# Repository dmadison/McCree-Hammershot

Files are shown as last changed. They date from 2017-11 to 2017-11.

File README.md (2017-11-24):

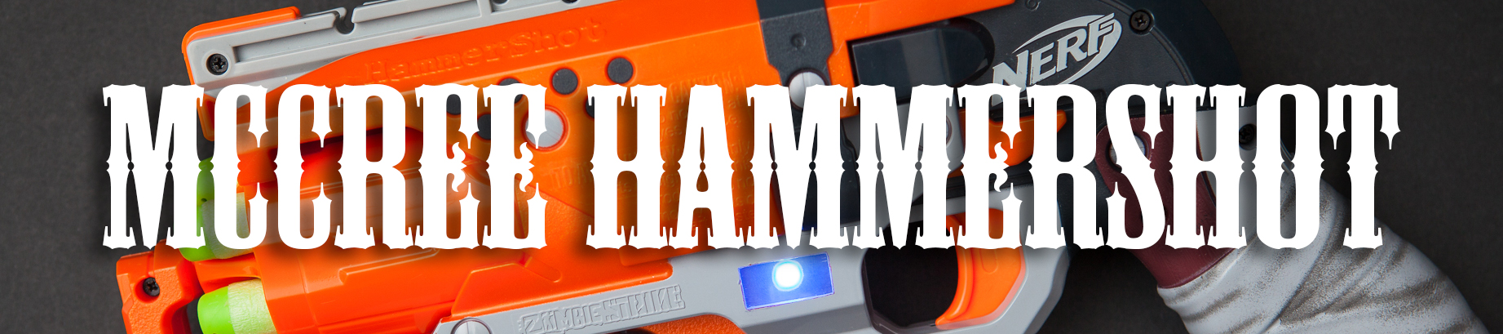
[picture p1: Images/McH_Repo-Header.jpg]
McCree Hammershot Header


## Synopsis
These are the associated files for my McCree Hammershot controller project! I turned a Nerf revolver into a custom controller for the character of [McCree](https://playoverwatch.com/en-us/heroes/mccree/) in *Overwatch*. The revolver contains an Arduino Pro Micro, an MPU-6050 IMU, and a host of other parts to handle McCree's controls. When paired with either a DDR dance pad or a Wii Nunchuk to handle his movement, I can use all of McCree's controls and play the game reasonably well.

For more information, check out the full build log on [PartsNotIncluded.com](http://www.partsnotincluded.com/projects/mccree-hammershot-controller/).

## Dependencies
The Hammershot program is dependent on the [CapacitiveSensor](https://github.com/PaulStoffregen/CapacitiveSensor/releases/tag/0.5.1), [Encoder](https://github.com/PaulStoffregen/Encoder/releases/tag/1.4.1) and [FastLED](https://github.com/FastLED/FastLED/releases/tag/v3.1.6) libraries. The Nunchuk code is dependent on the [WiiChuck](https://github.com/madhephaestus/WiiChuck/releases/tag/0.0.23) library to handle communication between the board and the Nunchuk. Both sketches are dependent on the Arduino IDE's built-in Keyboard, Mouse, and Wire libraries. The sketches were compiled using version 1.8.2 of the IDE.

I've linked to the specific library releases that work with this code. Note that future versions may not be compatible.

## License
The Arduino code, CAD files, and breakout PCB are licensed under the terms of the [GNU General Public License v3.0](https://www.gnu.org/licenses/gpl-3.0.en.html).

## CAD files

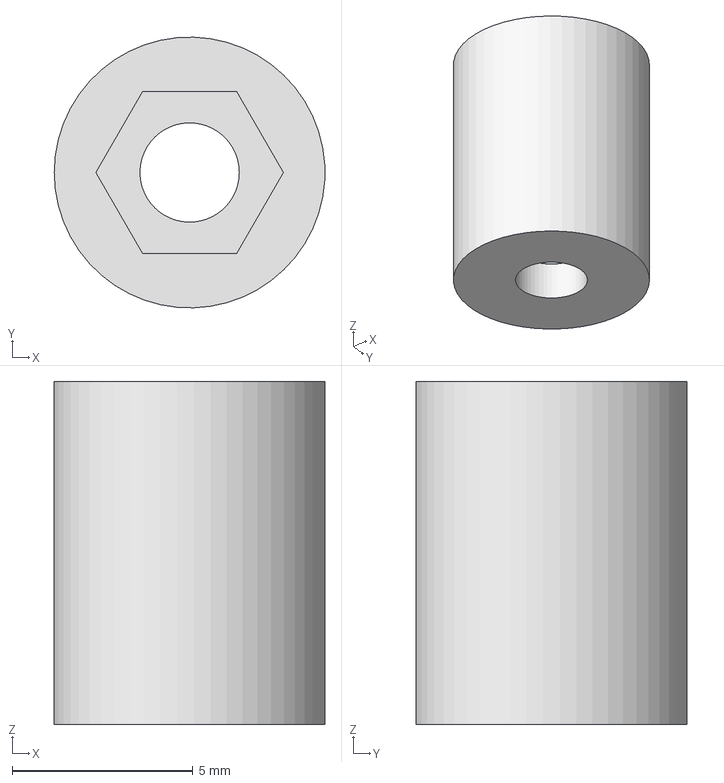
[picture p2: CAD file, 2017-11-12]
CAD/STEP/McH - Shell Connection Standoff.step
7.49 x 7.50 x 9.50 mm

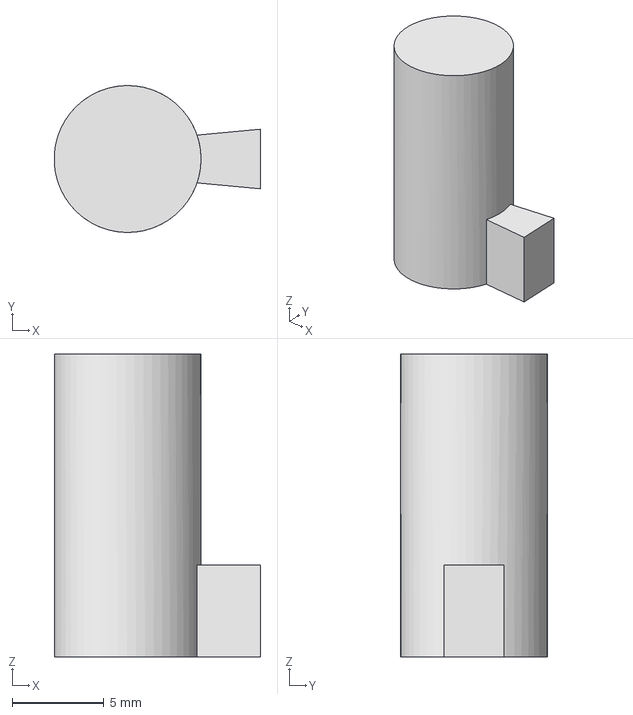
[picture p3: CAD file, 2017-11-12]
CAD/STEP/McH - Cylinder Wedge.step
11.2 x 8.00 x 16.5 mm

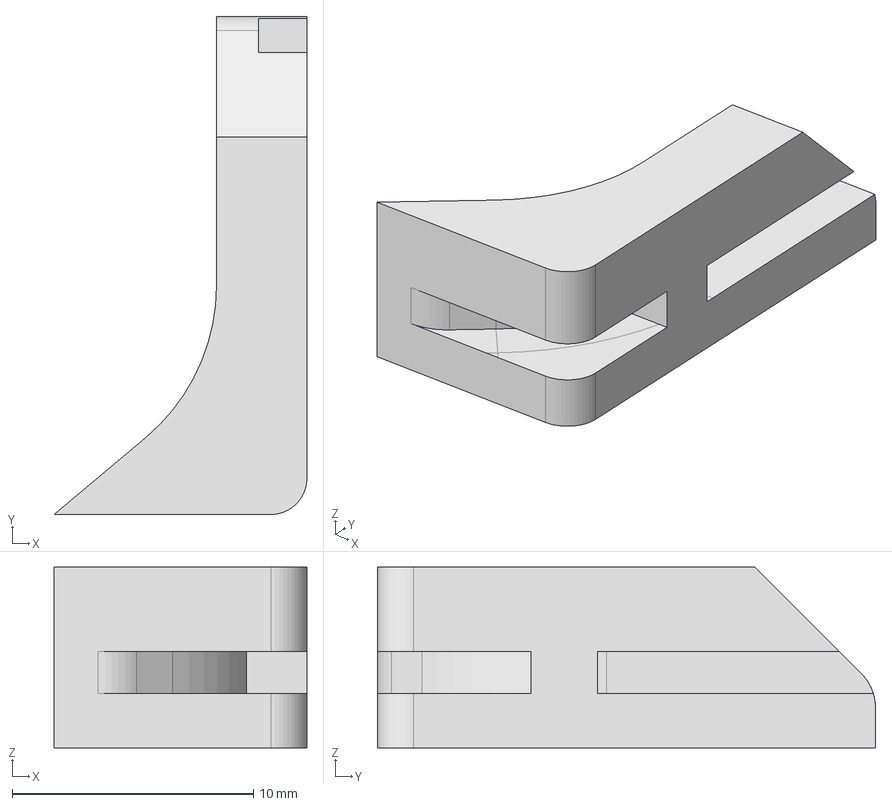
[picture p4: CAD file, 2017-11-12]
CAD/STEP/McH - Indicator Light Slot Support.step
10.5 x 20.7 x 7.50 mm

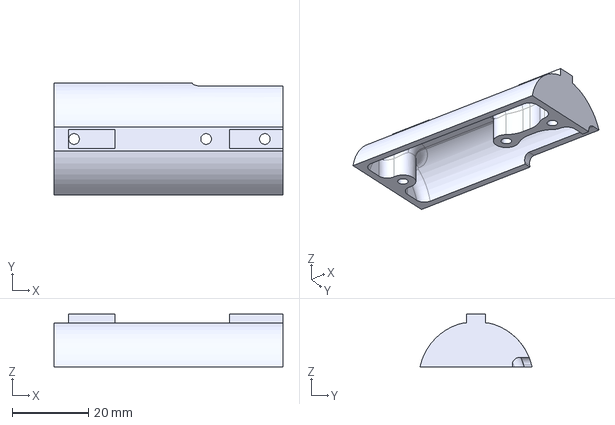
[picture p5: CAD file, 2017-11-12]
CAD/STEP/McH - PCB Mount.step
60.0 x 29.3 x 13.8 mm

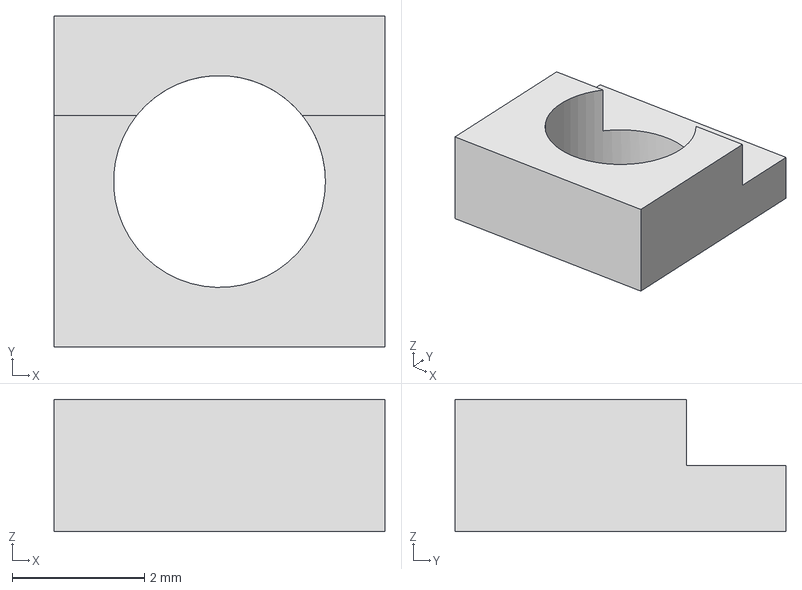
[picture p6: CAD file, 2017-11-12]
CAD/STEP/McH - MPU Capacitor Spacer.step
5.00 x 5.00 x 2.00 mm

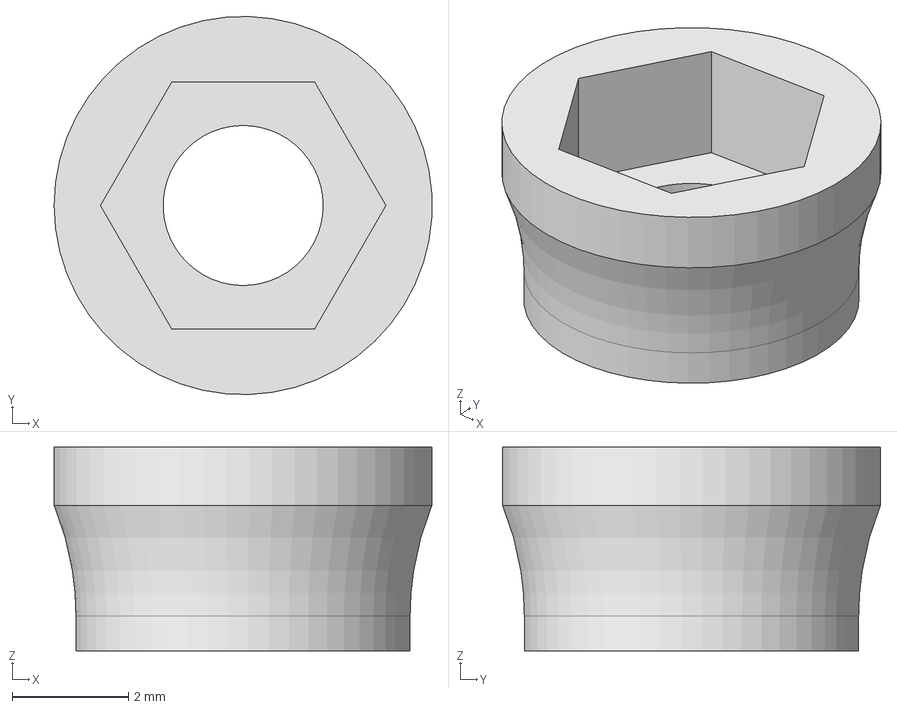
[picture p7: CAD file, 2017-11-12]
CAD/STEP/McH - Indicator Light Threaded Standoff.step
6.49 x 6.50 x 3.50 mm

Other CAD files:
CAD/STL/McH - Cylinder Wedge.stl
CAD/STL/McH - Indicator Light Slot Support.stl
CAD/STL/McH - Indicator Light Threaded Standoff.stl
CAD/STL/McH - MPU Capacitor Spacer.stl
CAD/STL/McH - PCB Mount.stl
CAD/STL/McH - Shell Connection Standoff.stl

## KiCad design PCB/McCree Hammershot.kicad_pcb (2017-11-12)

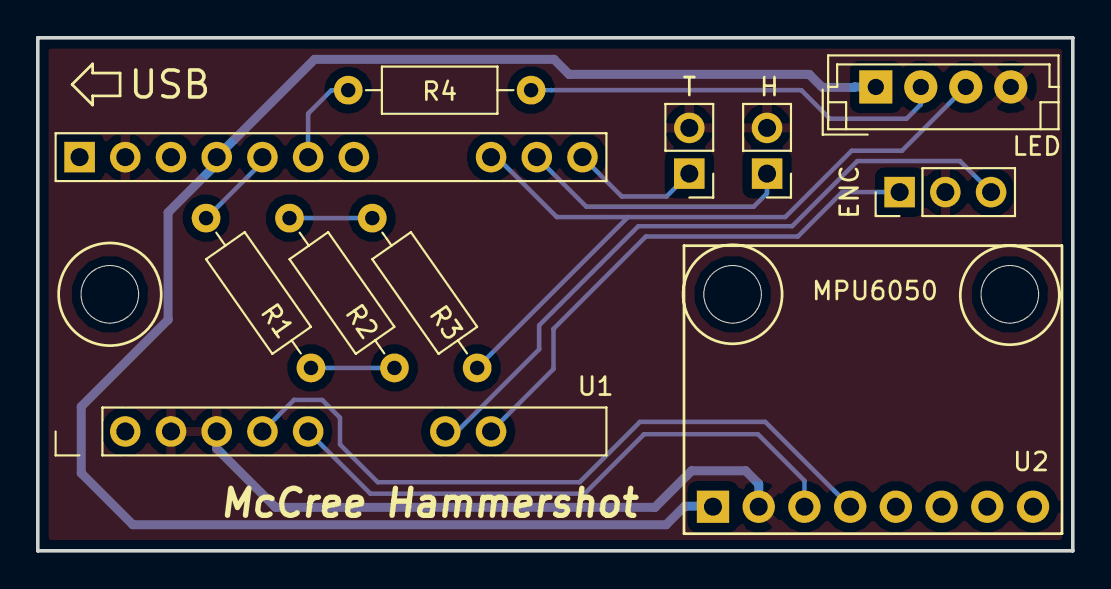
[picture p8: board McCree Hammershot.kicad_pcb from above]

Board: 4 copper layers, 57.5 x 28.5 mm, 10 parts (0 on the bottom side), 14 nets.

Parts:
ENC: Rotary Enc. Conn; Pin_Header_Straight_1x03_Pitch2.54mm
H: Hammer Conn; Pin_Header_Straight_1x02_Pitch2.54mm
LED: LED Conn; JST_EH_B04B-EH-A_04x2.50mm_Straight
R1, R2, R3: 1M; R_Axial_DIN0207_L6.3mm_D2.5mm_P10.16mm_Horizontal
R4: 470; R_Axial_DIN0207_L6.3mm_D2.5mm_P10.16mm_Horizontal
T: Trigger Conn; Pin_Header_Straight_1x02_Pitch2.54mm
U1: Arduino_Pro-Micro; Arduino_Pro-Micro_Headers_Gaps
U2: MPU6050; MPU6050_Breakout

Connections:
/+5V: LED.1, U1.VCC, U2.1
/CapSense: LED.3, R3.1, U1.14
/CapSource: R1.2, U1.A3
/EncoderA: ENC.1, U1.7
/EncoderB: ENC.3, U1.6
/GND: ENC.2, H.2, LED.4, T.2, U1.GND, U2.2
/Hammer: H.1, U1.16
/LED_Data: LED.2, R4.1
/SCL: U1.3, U2.3
/SDA: U1.2, U2.4
/Trigger: T.1, U1.10
unnamed: R1.1, R2.2
unnamed: R2.1, R3.2
unnamed: R4.2, U1.A2

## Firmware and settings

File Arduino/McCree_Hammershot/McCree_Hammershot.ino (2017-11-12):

/*
 *  Project     McCree Hammershot - Nerf Gun Code
 *  @author     David Madison
 *  @link       github.com/dmadison/McCree-Hammershot
 *  @license    GPLv3 - Copyright (c) 2017 David Madison
 *
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
 *  You should have received a copy of the GNU General Public License
 *  along with this program.  If not, see <http://www.gnu.org/licenses/>.
 */

#include <Wire.h>
#include <Mouse.h>
#include <Keyboard.h>

#include <Encoder.h>
#include <CapacitiveSensor.h>
#include <FastLED.h>

// -------- User Settings --------
// -- Game --
const float OverwatchSens = 7.5;   // User mouse sensitivity in Overwatch
const float AimSpeedFactor = 1.0;   // Factor to multiply aimspeed by
// -- LED --
const uint8_t LED_Brightness = 50;
const CRGB runningColor  = CRGB::Blue;
const CRGB pauseColor    = CRGB::Yellow;
const CRGB actionColor   = CRGB::Green;
const CRGB ultColor      = CRGB(0xFF3200); // Orange-ish red
const CRGB failsafeColor = CRGB::Purple;
// --------------------------------

// Tuning Options
const long    IMU_UpdateRate = 5;   // In milliseconds
const uint8_t FS_Sel = 1; // Gyroscope range select, 500°/s
const int16_t GyroZeroThreshold = 100 / (1 << FS_Sel); // Level below which to null inputs, adjusted for range
const int16_t Aim_ExponentialThreshold = 125; // Threshold before exponential aiming kicks in, in °/s
const float   Aim_ExponentFactor = 0.05; // Factor to multiply the exponent product by, scaled by sensitivity
const int16_t CapThreshold = 75;    // Threshold to 'pressed' (no units)
const int16_t EncoderThreshold = 8; // Threshold to reload (4 per detent)

// Debug Flags (uncomment to dd)
// #define DEBUG // Enable to use any prints
// #define DEBUG_ACCEL
// #define DEBUG_GYRO
// #define DEBUG_AIMING
// #define DEBUG_CAPSENSE

// Pin Definitions (do not change)
const uint8_t HammerButtonPin = 16;
const uint8_t TriggerButtonPin = 10;
const uint8_t EncoderAPin = 6;
const uint8_t EncoderBPin = 7;
const uint8_t LedPin = A2;
const uint8_t CapSourcePin = A3;
const uint8_t CapSensorPin = 14;

// Global Variables
const uint8_t MPU_addr = 0x68; // I2C address for the MPU
const int16_t Gyro_FullScaleRange[4] = {250, 500, 1000, 2000}; // Gyroscope ranges (in degrees per second)
long timestamp;
long lastUpdate;
long lastFlash;
long lastReload;

boolean ultActive = 0;
boolean triggerActive = 0;
boolean hammerActive = 0;

CRGB leds[1];
CRGB currentLED;

// Objects
CapacitiveSensor capButton = CapacitiveSensor(CapSourcePin, CapSensorPin);
Encoder cylinder(EncoderAPin, EncoderBPin);

#ifdef DEBUG
#define DEBUG_PRINT(x)   do {Serial.print(x);}   while(0)
#define DEBUG_PRINTLN(x) do {Serial.println(x);} while(0)
#else
#define DEBUG_PRINT(x)
#define DEBUG_PRINTLN(x)
#endif

void setup() {
#ifdef DEBUG
  Serial.begin(115200);
  while (!Serial); // Wait for connection
#endif

  pinMode(HammerButtonPin, INPUT_PULLUP);
  pinMode(TriggerButtonPin, INPUT_PULLUP);

  FastLED.addLeds<WS2812B, LedPin, GRB>(leds, 1);
  FastLED.setBrightness(LED_Brightness);

  if (digitalRead(TriggerButtonPin) == 0) {
    failsafe(); // Just in-case something goes wrong
  }

  mpuStart();

  capButton.set_CS_AutocaL_Millis(0xFFFFFFFF);  // turn off autocalibration
  capButton.set_CS_Timeout_Millis(10);
  cylinder.write(0); // Zero the encoder position
}

void loop() {
  timestamp = millis();

  if (timestamp >= lastUpdate + IMU_UpdateRate) {
    lastUpdate = timestamp;
    handleIMU();
  }

  buttonInputs();
  cylinderReload();

  updateLED();
}

void mpuStart() {
  Wire.begin();
  TWBR = 12; // 400 kHz bus speed

  Wire.beginTransmission(MPU_addr);
  Wire.write(0x6B);  // PWR_MGMT_1 register
  Wire.write(1);     // use GyX oscillator
  Wire.endTransmission(false); // Keep bus active

  Wire.beginTransmission(MPU_addr);
  Wire.write(0x1B);  // GYRO_CONFIG registers
  Wire.write(FS_Sel << 3);  // Gyroscope scale
  Wire.endTransmission(true);
}

void handleIMU() {
  int16_t ax, ay, az, gx, gy, gz;

  readMPU(ax, ay, az, gx, gy, gz);

  // If capacitive button is triggered, don't aim
  if (capRead() == true) {
    #ifdef DEBUG_AIMING
        Serial.println(F("Capsense triggered"));
    #endif
    currentLED = pauseColor;
  }
  else {
    aiming(gz, gx);
  }

  ultimate(ax, ay, az);
  flashbang(gy, ax);
}

boolean capRead() {
  const int16_t nSamples = 15;

  int16_t reading = capButton.capacitiveSensor(nSamples);

  #ifdef DEBUG_CAPSENSE
    if (reading >= CapThreshold) {
      Serial.print(F("ON"));
    }
    else {
      Serial.print(F("Off"));
    }
    Serial.print('\t');
    Serial.print(reading);
    Serial.print('\t');
    Serial.println(F("CapSens"));
  #endif

  // Hammer makes reading inaccurate
  if (reading >= CapThreshold && !hammerActive) {
    return true;
  }

  return false;
}

void readMPU(int16_t &aX, int16_t &aY, int16_t &aZ, int16_t &gX, int16_t &gY, int16_t &gZ) {
  const int16_t GyroCalX = -70;
  const int16_t GyroCalY = -50; // Nerf gun values
  const int16_t GyroCalZ = 35;

  int16_t MPU_temperature;
  int16_t *IMU_Data[7] = {&aX, &aY, &aZ, &MPU_temperature, &gX, &gY, &gZ};
  const int16_t GyroCalibration[3] = {
    GyroCalX / (1 << FS_Sel),
    GyroCalY / (1 << FS_Sel),
    GyroCalZ / (1 << FS_Sel),
  };

  Wire.beginTransmission(MPU_addr);
  Wire.write(0x3B);  // starting with register 0x3B (ACCEL_XOUT_H)
  Wire.endTransmission(false);

  Wire.requestFrom(MPU_addr, (uint8_t) 14, (uint8_t) true); // request a total of 14 registers

  for (int i = 0; i < 7; i++) {
    *IMU_Data[i] = Wire.read() << 8 | Wire.read(); // A-XYZ, TMP, and G-XYZ
  }

  reorientMPU(aX, aY, aZ, gX, gY, gZ);

  // Calibrate gyro axes and check for overflow
  for (int i = 4; i < 7; i++) {
    int32_t gyroTemp = (int32_t) * IMU_Data[i] + (int32_t) GyroCalibration[i - 4];

    if (gyroTemp > 32767) {
      *IMU_Data[i] = 32767;
    }
    else if (gyroTemp < -32768) {
      *IMU_Data[i] = -32768;
    }
    else {
      *IMU_Data[i] += GyroCalibration[i - 4];
      if (abs(*IMU_Data[i]) < GyroZeroThreshold) {
        *IMU_Data[i] = 0;
      }
    }
  }

  #ifdef DEBUG_ACCEL
    Serial.print(aX);
    Serial.print('\t');
    Serial.print(aY);
    Serial.print('\t');
    Serial.print(aZ);
    Serial.print('\t');
    Serial.print(F("XYZ Acc"));
    Serial.print('\n');
  #endif
  
  #ifdef DEBUG_GYRO
    Serial.print(gX);
    Serial.print('\t');
    Serial.print(gY);
    Serial.print('\t');
    Serial.print(gZ);
    Serial.print('\t');
    Serial.print(F("XYZ Gy"));
    Serial.print('\n');
  #endif
}

void reorientMPU(int16_t &aX, int16_t &aY, int16_t &aZ, int16_t &gX, int16_t &gY, int16_t &gZ) {
  // Reorient inputs from the position of the MPU to the expected coordinate system.
  // McCree Hammershot: Twist board +90° about Y. Z = X, X = -Z, Y doesn't change.

  int16_t tempAxis;

  // Reorient accelerometer
  tempAxis = aZ;
  aZ = aX;
  aX = ~tempAxis;

  // Reorient gyroscope
  tempAxis = gZ;
  gZ = gX;
  gX = ~tempAxis;
}

void aiming(int16_t gyX, int16_t gyY) {
  const float IMU_AngleChange = (float) Gyro_FullScaleRange[FS_Sel] / (1000.0 / (float) IMU_UpdateRate); // Convert °/s to degree change per time read
  const float IMU_Scale = IMU_AngleChange / 32768.0; // Convert angular change to int16_t scale
  const float OverwatchTPD = 54550.0 / 360.0; // Ticks per degree in Overwatch, at 1.0 sens.
  
  const float OverwatchConversion = (OverwatchTPD * AimSpeedFactor / OverwatchSens) * IMU_Scale; // 'Magic' variable representing the degree change in OW mouse ticks
  const float OW_ExponentialThreshold = (Aim_ExponentialThreshold / Gyro_FullScaleRange[FS_Sel]) * OverwatchConversion * 32768.0; // exponential aim threshold, in (overwatch ticks / max overwatch ticks per sample)
  const float Aim_ExponentFactorScale = Aim_ExponentFactor * (OverwatchSens / 7.5); // Set using 7.5 sensitivity 
  
  currentLED = runningColor;

  if (gyX == 0 && gyY == 0) {
    #ifdef DEBUG_AIMING
        Serial.println(F("Aim inputs 0"));
    #endif
    return; // No mouse movement
  }

  int16_t * xyInputs[2] = {&gyX, &gyY};
  float xyScaled[2];

  for (int i = 0; i < 2; i++) {
    if (*xyInputs[i] != 0) {
      xyScaled[i] = OverwatchConversion * (float) ~*xyInputs[i]; // Flip gyro inputs to match mouse axis, then calculate

      // Exponent function. Linear baseline + (squared baseline * minimizing factor)
      if(abs(xyScaled[i]) >= OW_ExponentialThreshold){    
        float mouseSign = 1; // Faster than x/|x|
        if(xyScaled[i] < 0){
          mouseSign = -1; 
        }
        
        xyScaled[i] +=
          abs(xyScaled[i] - OW_ExponentialThreshold) * abs(xyScaled[i] - OW_ExponentialThreshold) *
          Aim_ExponentFactorScale *
          mouseSign;
      }
    }
  }

  #ifdef DEBUG_AIMING
    Serial.print(xyScaled[0]);
    Serial.print('\t');
    Serial.print(xyScaled[1]);
    Serial.print('\t');
    Serial.print(F("XY Aiming"));
    Serial.print('\n');
  #endif

  sendMouse(xyScaled[0], xyScaled[1]);
}

void sendMouse(float mX, float mY){
  static float xyRemainder[2];

  float * flt_mouseXY[2] = {&mX, &mY};
  int32_t int_mouseXY[2] = {(int32_t) mX, (int32_t) mY};
    
  // Store floating point remainders and insert them if > 1
  for (int i = 0; i < 2; i++) {
    if (*flt_mouseXY[i] != 0) {
      float remainderTemp = *flt_mouseXY[i] - int_mouseXY[i];
      
      if (abs(remainderTemp) >= 0.05) {
        xyRemainder[i] += remainderTemp;
      }

      if (xyRemainder[i] > 1) {
        int_mouseXY[i] += 1;
        xyRemainder[i]--;
      }
      else if (xyRemainder[i] < -1) {
        int_mouseXY[i] -= 1;
        xyRemainder[i]++;
      }
    }
  }

  // Calculate +/- signs beforehand to save cycles
  int8_t mouseSign[2] = {1, 1};
  for(int i = 0; i < 2; i++){
    // Single if statement faster than x/|x|
    if(int_mouseXY[i] < 0){
      mouseSign[i] = -1;
    }
  }

  // Send mouse outputs in iterations, to avoid the int8_t limit of the Mouse.move function
  while(int_mouseXY[0]!= 0 || int_mouseXY[1] != 0){
    int8_t mouseUpdate[2];
    
    for(int i = 0; i < 2; i++){
      if(abs(int_mouseXY[i]) >= 127){
        mouseUpdate[i] = 127 * mouseSign[i];
        int_mouseXY[i] = (abs(int_mouseXY[i]) - 127) * (int32_t) mouseSign[i];
      }
      else if(abs(int_mouseXY[i]) > 0){
        mouseUpdate[i] = (int8_t) int_mouseXY[i];
        int_mouseXY[i] = 0;
      }
      else{
        mouseUpdate[i] = 0;
      }
    }
    Mouse.move(mouseUpdate[0], mouseUpdate[1]);
  }
}

void ultimate(int16_t ax, int16_t ay, int16_t az) {
  const int16_t Gravity = -16384; // Value of -1g on the +2/-2 scale
  const int16_t yAngleTolerance = 1000; // Tolerance on the Y-axis angle check (front to back)

  const int16_t xAngleTolerance = 2000; // Tolerance on the X-axis angle check (left to right)
  const int16_t zAngleTolerance = 4000; // Tolerance on the Z-axis angle check (top to bottom)
  const int16_t xNeutralPoint = -500;   // Offset because of the gun's center of mass
  const int16_t zNeutralPoint = -2200;  // Offset becasue of the gun's center of mass

  const uint16_t ultTimeThreshold = 10; // Trigger time in milliseconds
  const long     ultDebounce = 700;     // Debounce time, in milliseconds

  static uint16_t timeCounter = 0;
  long  lastUlt = 0;

  if (ultActive) {
    lastUlt = lastUpdate;
  }

  if (
    ultActive != true &&
    ay <= Gravity + yAngleTolerance &&
    ay >= Gravity - yAngleTolerance &&

    ax <= xNeutralPoint + xAngleTolerance &&
    ax >= xNeutralPoint - xAngleTolerance &&

    az <= zNeutralPoint + zAngleTolerance &&
    az >= zNeutralPoint - zAngleTolerance
  ) {
    timeCounter++;
    if (
      timeCounter >= (ultTimeThreshold / IMU_UpdateRate) &&
      lastUpdate >= lastUlt + ultDebounce
    ) {
      Keyboard.press('q');
      Keyboard.release('q');
      FastLED.setBrightness(255);
      ultActive = true;
    }
  }
  else {
    timeCounter = 0;
  }
}

void flashbang(int16_t gy, int16_t ac) {
  const int16_t flashThresholdG = 22000 / (1 << FS_Sel); // Gyro threshold, adjusted for range
  const int16_t flashThresholdA = -26000; // Accelerometer threshold, 1.6 g
  const long    flashDebounce = 100;     // Debounce time, in milliseconds

  if (gy >= flashThresholdG && ac <= flashThresholdA) {
    if (lastUpdate >= lastFlash + flashDebounce) {
      Keyboard.press('e');
      Keyboard.release('e');
      lastFlash = lastUpdate;
      cylinder.write(0);
    }
  }
}

void buttonInputs() {
  boolean triggerRead = digitalRead(TriggerButtonPin);
  boolean hammerRead = digitalRead(HammerButtonPin);

  if (triggerRead == 0) {
    if (triggerActive == 0) {
      Mouse.press();
      triggerActive = 1;
      if (!ultActive) {
        capButton.reset_CS_AutoCal();
      }
      ultActive = false;
      FastLED.setBrightness(LED_Brightness);
    }
  }
  else if (triggerActive == 1) {
    Mouse.release();
    triggerActive = 0;
  }

  if (hammerRead == 0) {
    if (hammerActive == 0) {
      Mouse.press(MOUSE_RIGHT);
      hammerActive = 1;
      ultActive = false;
      FastLED.setBrightness(LED_Brightness);
    }
  }
  else if (hammerActive == 1) {
    Mouse.release(MOUSE_RIGHT);
    hammerActive = 0;
  }
}

void cylinderReload() {
  const long flashTimeout = 150;

  if (timestamp <= lastFlash + flashTimeout ) {
    cylinder.write(0);
    return;
  }

  int16_t newPosition = cylinder.read();

  if (newPosition >= EncoderThreshold || newPosition <= -EncoderThreshold) {
    Keyboard.press('r');
    Keyboard.release('r');
    lastReload = timestamp;
    capButton.reset_CS_AutoCal();
    cylinder.write(0); // Zero the encoder position
  }
}

void updateLED() {
  long ledHangTime = 150; // LED persist for flash and reload (ms)

  if (ultActive == true) {
    currentLED = ultColor;
  }
  else if (
    triggerActive
    || hammerActive
    || timestamp <= lastFlash + ledHangTime
    || timestamp <= lastReload + ledHangTime
  ) {
    currentLED = actionColor;
  }

  if (currentLED != leds[0]) {
    leds[0] = currentLED;
    FastLED.show();
  }
}

void failsafe() {
  const uint16_t FadeTime = 2000; // Total fade cycle time
  const uint8_t  MaxBrightness = 127;
  const uint8_t  MinBrightness = 10;

  leds[0] = failsafeColor;
  DEBUG_PRINTLN(F("Failsafe triggered. Code will not execute"));

  for (;;) {
    for (int i = MinBrightness; i < MaxBrightness; i++) {
      FastLED.setBrightness(i);
      FastLED.show();
      delay(FadeTime / (MaxBrightness - MinBrightness));
    }

    for (int i = MaxBrightness; i > MinBrightness; i--) {
      FastLED.setBrightness(i);
      FastLED.show();
      delay(FadeTime / (MaxBrightness - MinBrightness));
    }
  }
}

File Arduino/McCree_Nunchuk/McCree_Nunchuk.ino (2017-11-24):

/*
 *  Project     McCree Hammershot - Nunchuk Code
 *  @author     David Madison
 *  @link       github.com/dmadison/McCree-Hammershot
 *  @license    GPLv3 - Copyright (c) 2017 David Madison
 *
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
 *  You should have received a copy of the GNU General Public License
 *  along with this program.  If not, see <http://www.gnu.org/licenses/>.
 */

#include <Wire.h>
#include <Keyboard.h>
#include <WiiChuck.h>
#include "button.h"

Nunchuck nunchuk;

button moveForward('w');
button moveLeft('a');
button moveBack('s');
button moveRight('d');

button jump(' ');
button roll(KEY_LEFT_SHIFT);
button commWheel('c');

button scoreboard(KEY_TAB);

void setup() {
  // Safety check. Ground pin 9 to stop inputs.
  pinMode(9, INPUT_PULLUP);
  if(digitalRead(9) == 0){
    for(;;){}
  }

  setMultiplexer();
  nunchuk.begin();

  if(nunchuk.getButtonZ() && nunchuk.getButtonC()){
    // Nunchuk disconnected or both buttons pressed on startup
    for(;;){}
  }
}

void loop() {
  if(nunchuk.readData()){
    joyWASD((uint8_t) nunchuk.getJoyX(), (uint8_t) nunchuk.getJoyY());
    handleButtons(nunchuk.getButtonC(), nunchuk.getButtonZ());
    handleAccel(nunchuk.getAccelY());
  }
  else{
    releaseAll();
  }
}

void joyWASD(uint8_t x, uint8_t y){
  button * movementKeys[4] = {&moveRight, &moveLeft, &moveForward, &moveBack}; // X+, X-, Y+, Y-
  const uint8_t joyDeadzone = 60; // +/-, centered at 127

  uint8_t joyXY[2] = {x, y};

  for(int i = 0; i < 2; i++){
    movementKeys[i*2]->press(joyXY[i] >= 127 + joyDeadzone);
    movementKeys[i*2 + 1]->press(joyXY[i] <= 127 - joyDeadzone);
  }
}

void handleButtons(boolean bC, boolean bZ){
  if(bC && bZ){
    commWheel.press(true);
  }
  else{
    commWheel.press(false);
    roll.press(bC);
    jump.press(bZ);
  }
}

void handleAccel(uint16_t aY){
  const uint16_t accelThreshold = 360; // Controller pointed up
  const uint8_t countThreshold = 6; // Arbitrary limit to filter noise
  
  static uint8_t ayCount = 0;
  
  if(aY <= accelThreshold){
    ayCount++;
    if(ayCount >= 6){
      scoreboard.press(true);
      ayCount = 6;
    }
  }
  else{
    ayCount = 0;
    scoreboard.press(false);
  }
}

void setMultiplexer(){
  Wire.begin();

  Wire.beginTransmission(0x70);
  Wire.write(1 << 0); // Switch to port 0
  Wire.endTransmission();  
}

void pressAll(boolean p){
  moveForward.press(p);
  moveLeft.press(p);
  moveBack.press(p);
  moveRight.press(p);
  
  jump.press(p);
  roll.press(p);
  commWheel.press(p);
  
  scoreboard.press(p);
}

void releaseAll(){
  pressAll(false);
}

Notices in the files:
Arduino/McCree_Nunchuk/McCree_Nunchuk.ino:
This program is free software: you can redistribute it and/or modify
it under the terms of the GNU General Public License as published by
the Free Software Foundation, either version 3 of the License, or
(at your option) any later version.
